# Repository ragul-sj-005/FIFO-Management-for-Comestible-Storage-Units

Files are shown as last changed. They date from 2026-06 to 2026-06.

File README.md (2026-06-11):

# FIFO Management for Comestible Storage Units

## Design and Implementation of a Smart Interface for Automating FIFO Stock Control in Comestible Storage Units

---

## Overview

This project is a Raspberry Pi based smart inventory management system designed for commercial kitchens, hotels, restaurants, canteens, and food storage facilities. The system automates the **First-In First-Out (FIFO)** inventory principle by tracking food items through QR codes, monitoring expiry times, and providing visual and audible alerts.

The system uses:

* Raspberry Pi 5
* HDMI Main Display
* 3.5-inch SPI Secondary Display
* USB Camera
* Thermal QR Printer
* Rotary Encoders
* Inductive Proximity Sensor
* Buzzer
* LED Indicators

The objective is to minimize food wastage, improve stock traceability, and simplify inventory management operations.

---

## Features

### FIFO Inventory Management

* Automatic FIFO tracking.
* Every food item receives a unique QR code.
* Oldest stock can be identified and removed first.

### QR Code Based Tracking

* Generates unique QR IDs.
* Prints QR labels using thermal printer.
* QR scanning updates inventory automatically.

### Expiry Monitoring

* Tracks shelf life of each food item.
* Detects expired inventory automatically.
* Generates alarm notifications.

### Dual Display Architecture

#### HDMI Display (Main Interface)

* Live inventory table
* Camera feed
* Item status monitoring
* Printer status
* Sensor status
* Alarm status

#### 3.5" SPI Display (Secondary Interface)

* Encoder-based setup screen
* Weight adjustment interface
* Camera preview
* Status notifications

### Weight Management

* Rotary encoder based weight selection
* Weight update after scanning QR codes
* Real-time synchronization between displays

### Alarm Management

* Buzzer alerts for expired items
* Temporary silence feature
* Automatic re-alert if expired item remains
* Permanent alarm cancellation when expired item is removed

### Shared State Synchronization

* Thread-safe state management
* Atomic JSON communication
* Inter-process communication between displays

---

# System Architecture

```
                      ┌────────────────────┐
                      │     USB Camera     │
                      └─────────┬──────────┘
                                │
                                ▼
                     ┌─────────────────────┐
                     │   HDMI Display App  │
                     │   hdmi_display.py   │
                     └─────────┬───────────┘
                               │
          ┌────────────────────┼────────────────────┐
          │                    │                    │
          ▼                    ▼                    ▼

   QR Printer         Shared State          Proximity Sensor
                         JSON File

          ▲                    ▲
          │                    │
          │                    │
          ▼                    ▼

                  Small Display App
                   small_display.py

          ▲                    ▲
          │                    │
          ▼                    ▼

      Encoder 1            Encoder 2
      (Weight)             (Item Select)
```

---

# Project Structure

```
FIFO-System/
│
├── hdmi_display.py
├── small_display.py
├── shared_state.py
│
├── README.md
│
└── assets/
    ├── images/
    └── diagrams/
```

---

# Core Modules

## 1. shared_state.py

Acts as the central communication layer between both display applications.

### Responsibilities

* Stores inventory database
* Maintains display states
* Tracks encoder values
* Handles buzzer status
* Manages QR counters
* Synchronizes data across processes

### IPC Files

```
/tmp/fifo_state.json
```

Stores system state.

```
/dev/shm/fifo_frame.npy
```

Stores live camera frames in RAM.

---

## 2. hdmi_display.py

Main application running on the HDMI display.

### Functions

* Inventory dashboard
* QR code scanning
* Camera processing
* Expiry monitoring
* Thermal printer control
* Proximity sensor handling
* Buzzer control

### Display Information

* Inventory table
* QR IDs
* Item names
* Weight
* Shelf life
* Time remaining
* Expiry status

---

## 3. small_display.py

Secondary display application.

### Functions

* Encoder interface
* Weight adjustment
* Item selection
* Camera preview
* Status messages

### Supported Modes

| Mode | Function |
| --- | --- |
| startup | System startup |
| idle | Waiting state |
| setup | Add item |
| update | Update weight |
| camera | Live camera |
| printing | QR printing |
| fresh_scan | Fresh item removed |
| expired_scan | Expired item discarded |
| timeout | Expiry alert |

---

# Hardware Components

| Component | Purpose |
| --- | --- |
| Raspberry Pi 5 | Main Controller |
| HDMI Display | Main Dashboard |
| 3.5" SPI TFT Display | Secondary Interface |
| USB Camera | QR Scanning |
| Thermal Printer | QR Label Printing |
| Rotary Encoder 1 | Weight Selection |
| Rotary Encoder 2 | Item Selection |
| Inductive Sensor | Item Detection |
| Buzzer | Expiry Alert |
| LED | Sensor Status |

---

# GPIO Configuration

## HDMI Controller

| Device | GPIO |
| --- | --- |
| Sensor | GPIO 16 |
| Buzzer | GPIO 12 |
| LED | GPIO 13 |

## Small Display

### Encoder 1

| Signal | GPIO |
| --- | --- |
| CLK | GPIO 19 |
| DT | GPIO 20 |
| SW | GPIO 5  |

### Encoder 2

| Signal | GPIO |
| --- | --- |
| CLK | GPIO 21 |
| DT | GPIO 26 |
| SW | GPIO 6  |

---

# Inventory Workflow

## Adding a New Item

1. Press SPACE.
2. System enters setup mode.
3. Encoder 2 selects food item.
4. Encoder 1 selects weight.
5. Press SPACE again.
6. QR label is printed.
7. Item is stored in inventory database.

---

## Updating an Existing Item

1. Place item near scanner.
2. QR code is detected.
3. System enters update mode.
4. Encoder 1 adjusts weight.
5. Press Encoder 1 switch.
6. Database updates weight.

---

## Expiry Detection

1. Expiry thread continuously checks inventory.
2. Expired items are flagged.
3. Buzzer activates.
4. Alert displayed on screens.
5. Scanning expired item removes it from database.

---

# Software Requirements

## Operating System

* Raspberry Pi OS Bookworm

## Python Version

```
Python 3.11+
```

## Required Libraries

```bash
pip install numpy
pip install pillow
pip install opencv-python
pip install pyzbar
pip install python-escpos
pip install rpi-lgpio
```

---

# Installation

Clone repository:

```bash
git clone https://github.com/yourusername/FIFO-Comestible-Storage.git

cd FIFO-Comestible-Storage
```

Install dependencies:

```bash
pip install -r requirements.txt
```

Run HDMI application:

```bash
python3 hdmi_display.py
```

Run Small Display:

```bash
sudo python3 small_display.py
```

---

# Communication Mechanism

The system uses a lightweight Inter-Process Communication (IPC) mechanism.

### State Communication

```
/tmp/fifo_state.json
```

Stores:

* Inventory database
* Display mode
* Encoder values
* Alarm state
* Active QR ID

### Camera Communication

```
/dev/shm/fifo_frame.npy
```

Stores live camera frames in RAM.

Benefits:

* Extremely fast
* No SD card wear
* Atomic state updates
* Reliable synchronization

---

# Safety Features

* Thread-safe shared state
* Atomic file writes
* Automatic buzzer reset
* Printer failure handling
* Camera failure recovery
* GPIO cleanup on shutdown
* QR scan cooldown protection

---

# Future Improvements

* Cloud inventory synchronization
* Mobile application integration
* RFID support
* AI-based food spoilage prediction
* Temperature and humidity monitoring
* Multi-storage unit networking
* Database backend (SQLite/PostgreSQL)
* Web dashboard

---

# Applications

* Hotels
* Restaurants
* Industrial Kitchens
* Catering Services
* Food Warehouses
* Hospitals
* Hostels
* Supermarkets

---

# Authors

Developed as part of a smart automation project for:

**FIFO Management of Comestible Storage Units**

Focused on reducing food wastage, improving traceability, and ensuring efficient stock rotation through automation.

---

# License

This project is released under the MIT License.

Feel free to use, modify, and distribute the software for educational and research purposes.

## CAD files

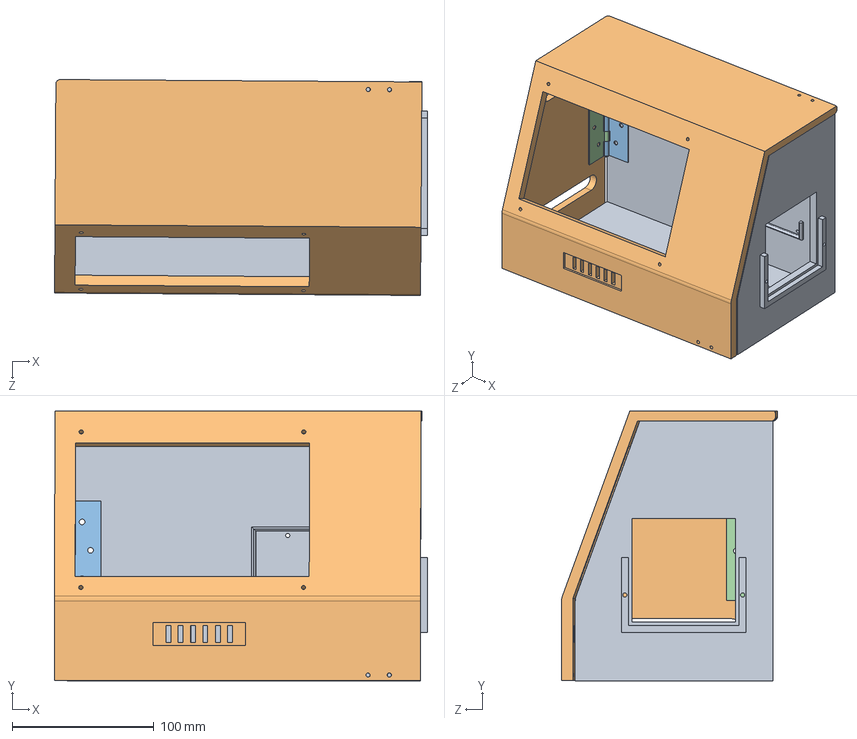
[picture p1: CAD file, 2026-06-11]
FIFO_Optimised_2.SLDASM
262.9 x 190.1 x 152.2 mm
Envelope_Opti_2_1
Envelope_Opti_2_2
Hinge_1
Hinge_2
Hinge_Centre_Rod

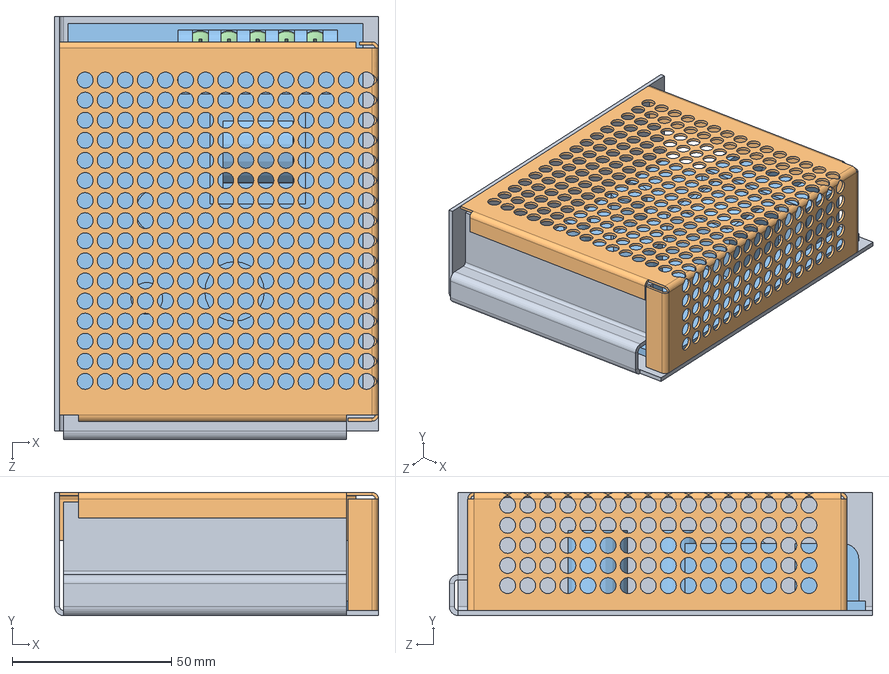
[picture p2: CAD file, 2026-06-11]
SMPS-24v.SLDASM
101.6 x 38.6 x 132.8 mm
Smps part 1-edit-00
Smps part 2-edit-00
part3-edit-00
pan cross head_am x 5

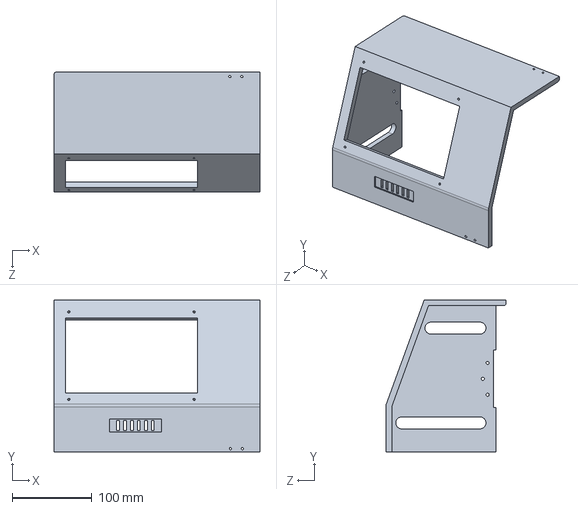
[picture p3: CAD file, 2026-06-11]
Envelope_Opti_2_2.SLDPRT
258.0 x 190.0 x 150.9 mm

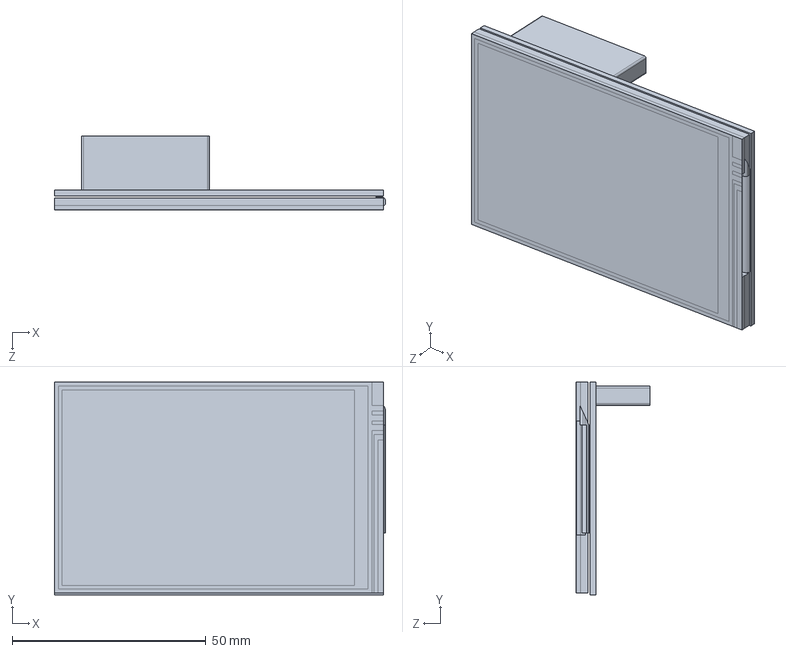
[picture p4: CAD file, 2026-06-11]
3.5' RPi TouchScreen v4.SLDPRT
85.5 x 55.0 x 19.1 mm

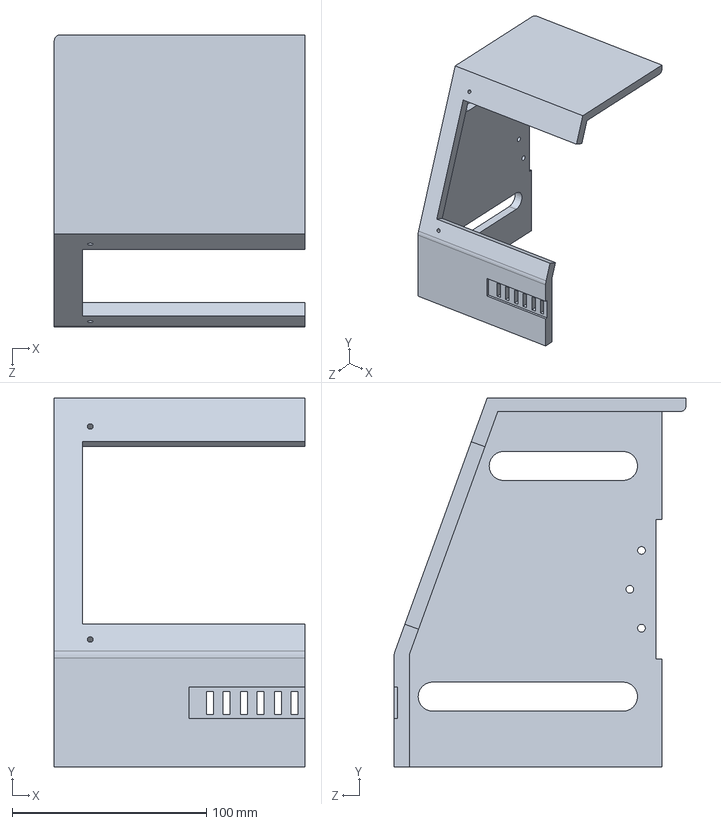
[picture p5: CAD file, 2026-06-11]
Envelope_Opti_2_2_2.SLDPRT
129.0 x 190.0 x 150.5 mm

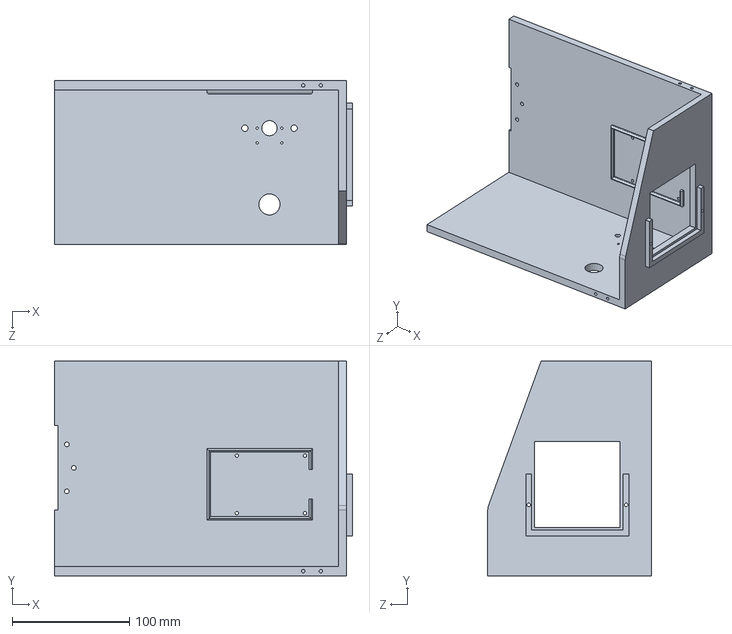
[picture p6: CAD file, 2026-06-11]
Envelope_Opti_2_1.SLDPRT
254.0 x 183.0 x 139.5 mm

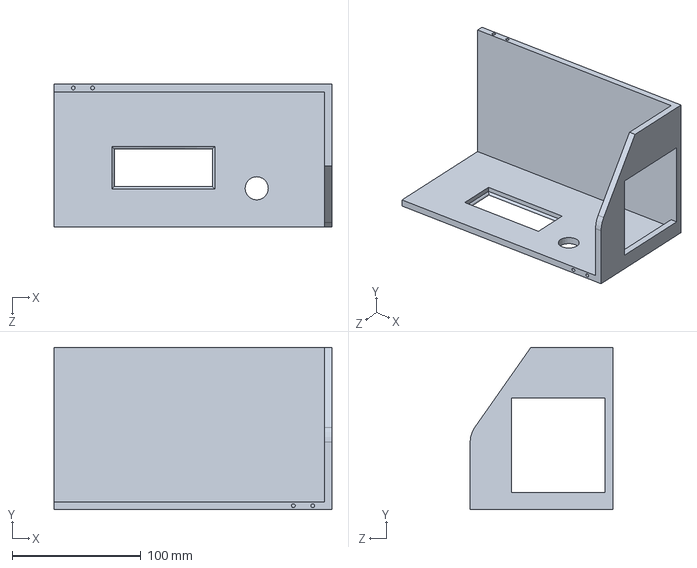
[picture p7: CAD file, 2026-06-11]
Back_Part_Mini_Review_2.SLDPRT
216.0 x 126.0 x 111.0 mm

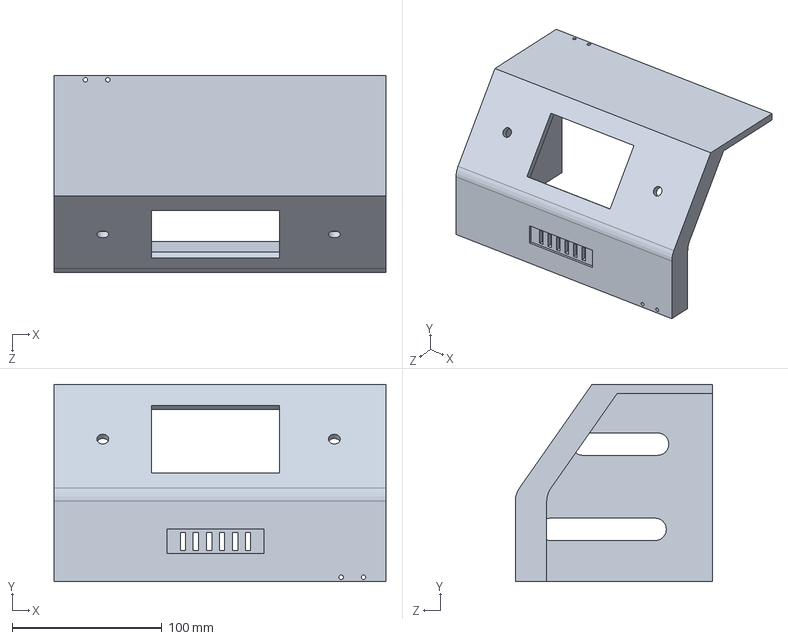
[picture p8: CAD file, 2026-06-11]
Front_Part_Mini_Review_2.SLDPRT
222.0 x 132.0 x 132.0 mm

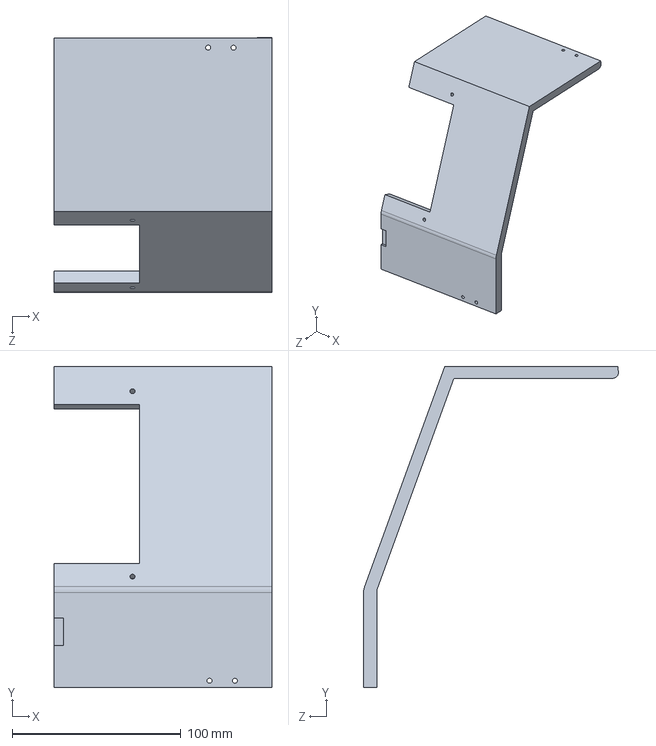
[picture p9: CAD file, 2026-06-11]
Envelope_Opti_2_2_1.SLDPRT
129.0 x 190.0 x 150.9 mm

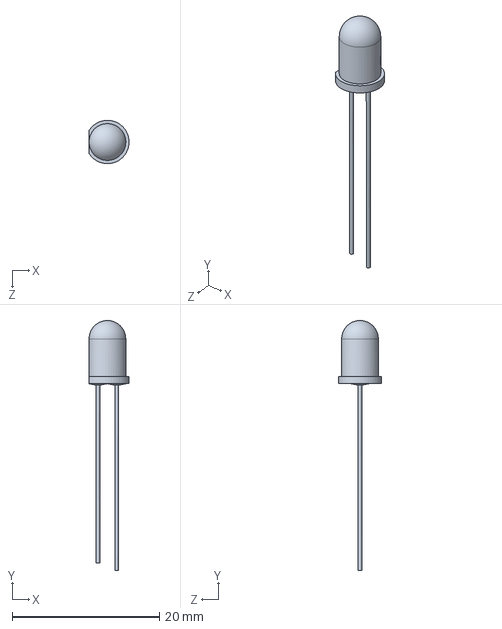
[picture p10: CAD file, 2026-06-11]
5mm_LED.SLDPRT
5.47 x 34.0 x 5.90 mm

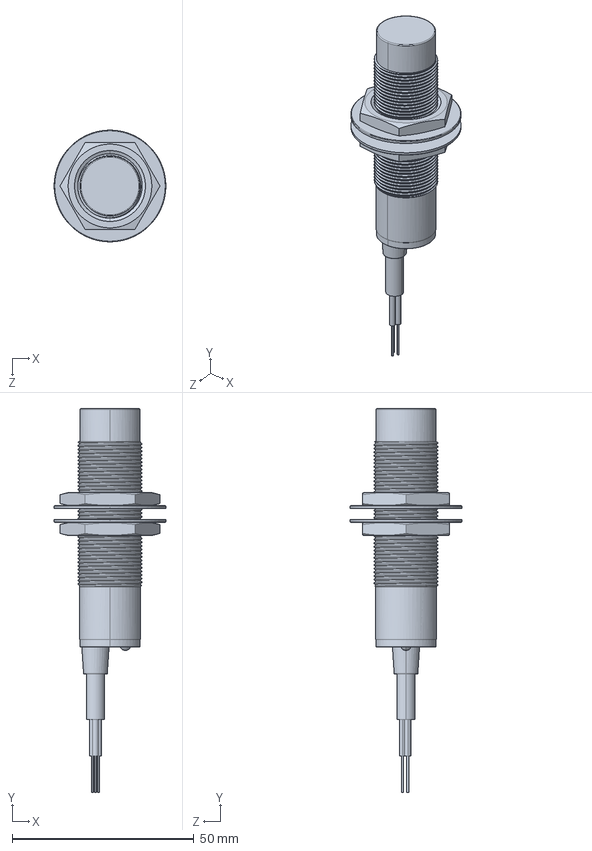
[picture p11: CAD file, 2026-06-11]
LJ18A3-8-Z.SLDPRT
30.7 x 105.5 x 30.7 mm

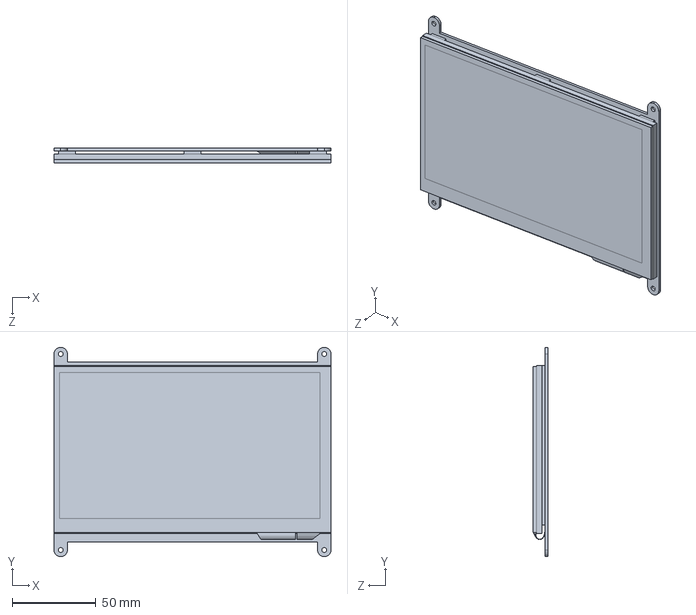
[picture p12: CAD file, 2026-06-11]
7inch Display-B 800X480px rev3.5.SLDPRT
164.9 x 124.7 x 8.75 mm

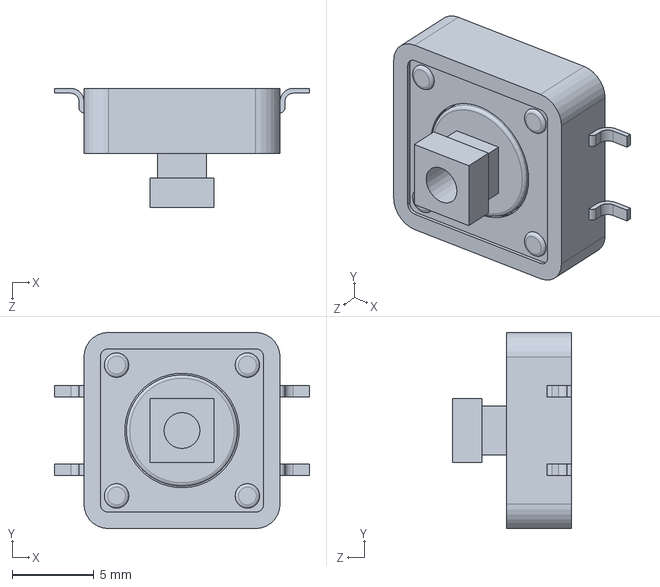
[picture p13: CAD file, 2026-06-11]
Trigger_Button.SLDPRT
15.6 x 12.0 x 7.30 mm

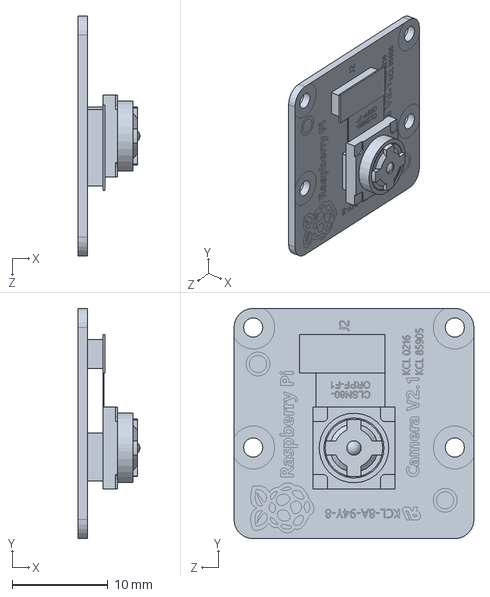
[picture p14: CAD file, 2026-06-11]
Pi_Camera.SLDPRT
6.45 x 24.0 x 25.0 mm

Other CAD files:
SMPS_Final.SLDPRT
Thermal_Printer.SLDPRT

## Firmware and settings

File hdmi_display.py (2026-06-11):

"""
hdmi_display.py  —  v4  (corrected)
═══════════════════════════════════════════════════════════════════
Main control panel — HDMI display, 800×480, fullscreen.

Hardware
─────────
  • USB Webcam       cv2.VideoCapture(0)
  • Inductive Sensor GPIO 16 BCM — active HIGH, PUD_DOWN
  • Buzzer           GPIO 12 BCM — active HIGH
  • LED              GPIO 13 BCM — active HIGH
  • Printer          /dev/ttyUSB0  9600 baud  FT232R adapter

Keyboard (temporary — replace with GPIO buttons later)
───────────────────────────────────────────────────────
  SPACE  → Button 1 — enter setup mode / confirm + print QR
  DELETE → Button 2 — remove table-selected item completely
  ESC    → Button 3 — remove active_qr_id (last scanned item) from database

Workflow
────────
  1. Startup      → GUI shown, table empty, camera blank
  2. Press SPACE  → enter setup mode (small display shows split screen)
                    Encoder 2 selects item, Encoder 1 sets weight
  3. Press SPACE  → confirm → print QR → item added to table
  4. Sensor HIGH  → camera ON, QR scanning active
  5. Scan existing QR → small display shows item+weight, Encoder 1 adjusts
                        weight, Encoder 1 SW confirms update
  6. Scan expired QR  → item removed, buzzer stops permanently for that item
  7. Press DELETE while item highlighted → remove item immediately

Table columns: QR ID | Item | Weight | Shelf Life | Time Left | Status

Buzzer
───────
  Rings once per expired item.
  Any button press silences — re-rings 60s later if item still expired.
  Scanning expired QR stops buzzer permanently for that item.

Fixes vs v3
───────────
  • GPIO.cleanup() removed from _gpio_init() — was resetting small_display's
    encoder pins at startup, causing random encoder death.
    GPIO.cleanup() is now ONLY called in the final shutdown finally block.
  • _buzzer_silenced_at defined and properly wired: silence_buzzer() records
    the timestamp so check_expiry_loop's BUZZER_RERING guard works correctly.
    Previously _buzzer_silenced_at was used but never defined → NameError crash.
  • buzzer_silenced_request flag is cleared immediately after being acted on,
    preventing it from repeatedly triggering silence_buzzer() on every poll.
"""

import logging
import os
import threading
import time
from datetime import datetime, timedelta

import cv2
import numpy as np
import tkinter as tk
from tkinter import ttk, messagebox
from PIL import Image, ImageTk

import RPi.GPIO as GPIO
from pyzbar.pyzbar import decode
from escpos.printer import Serial

import shared_state as state

# ══════════════════════════════════════════════════════════════════════════════
# LOGGING
# ══════════════════════════════════════════════════════════════════════════════
logging.basicConfig(level=logging.INFO,
                    format="%(asctime)s [%(levelname)s] %(message)s")
log = logging.getLogger("fifo.hdmi")

# ══════════════════════════════════════════════════════════════════════════════
# CONFIGURATION
# ══════════════════════════════════════════════════════════════════════════════
PIN_SENSOR      = 16
PIN_BUZZER      = 12
PIN_LED         = 13
BUZZER_DURATION = 10       # seconds buzzer rings before auto-off
BUZZER_RERING   = 60       # seconds before re-ring if item still expired

PRINTER_PORT    = "/dev/ttyUSB0"
PRINTER_BAUD    = 9600
CAMERA_INDEX    = 0
SCAN_COOLDOWN   = 2.0
MAX_ITEMS       = 20

# ══════════════════════════════════════════════════════════════════════════════
# GPIO SETUP
# ──────────────────────────────────────────────────────────────────────────────
# FIX: GPIO.cleanup() is NOT called here.
# Calling cleanup() at startup would reset the encoder pins that small_display
# already configured, causing random encoder failures and unstable pullups.
# cleanup() is only called once — in the final shutdown (see main() finally).
# ══════════════════════════════════════════════════════════════════════════════
def _gpio_init():
    GPIO.setmode(GPIO.BCM)
    GPIO.setwarnings(False)
    GPIO.setup(PIN_SENSOR, GPIO.IN,  pull_up_down=GPIO.PUD_UP)   # NC sensor — resting HIGH, LOW = triggered
    GPIO.setup(PIN_BUZZER, GPIO.OUT, initial=GPIO.LOW)
    GPIO.setup(PIN_LED,    GPIO.OUT, initial=GPIO.LOW)
    GPIO.output(PIN_BUZZER, GPIO.LOW)
    GPIO.output(PIN_LED,    GPIO.LOW)
    time.sleep(0.2)

# ══════════════════════════════════════════════════════════════════════════════
# PRINTER
# ══════════════════════════════════════════════════════════════════════════════
printer    = None
printer_ok = False

def _init_printer():
    global printer, printer_ok
    try:
        printer    = Serial(devfile=PRINTER_PORT, baudrate=PRINTER_BAUD, timeout=1)
        time.sleep(0.5)
        printer_ok = True
        log.info("Printer ready on %s", PRINTER_PORT)
    except Exception as e:
        printer_ok = False
        log.warning("Printer offline: %s", e)

# ══════════════════════════════════════════════════════════════════════════════
# BUZZER
# ──────────────────────────────────────────────────────────────────────────────
# FIX: _buzzer_silenced_at tracks when the buzzer was last silenced.
# This is used in check_expiry_loop to enforce BUZZER_RERING cooldown after
# a manual silence. Previously this variable was referenced but never defined,
# causing a NameError crash on the first expiry event.
# ══════════════════════════════════════════════════════════════════════════════
_buzzer_lock       = threading.Lock()
_buzzer_ringing    = False
_buzzer_silenced_at = [0.0]   # mutable container so inner functions can write it

def _buzzer_off_worker():
    global _buzzer_ringing
    time.sleep(BUZZER_DURATION)
    GPIO.output(PIN_BUZZER, GPIO.LOW)
    state.set_val("buzzer_active", False)
    state.write_state_file()
    with _buzzer_lock:
        _buzzer_ringing = False
    log.info("Buzzer auto-off")

def trigger_buzzer():
    global _buzzer_ringing
    with _buzzer_lock:
        if _buzzer_ringing:
            return
        _buzzer_ringing = True
    GPIO.output(PIN_BUZZER, GPIO.HIGH)
    state.set_val("buzzer_active", True)
    state.write_state_file()
    threading.Thread(target=_buzzer_off_worker, daemon=True).start()
    log.info("Buzzer triggered")

def silence_buzzer():
    """
    Silence buzzer on any button press.
    Records the silence timestamp so re-ring cooldown works correctly.
    Re-ring happens after BUZZER_RERING seconds if item is still expired.
    """
    global _buzzer_ringing
    GPIO.output(PIN_BUZZER, GPIO.LOW)
    state.set_val("buzzer_active", False)
    state.clear_all_buzzer_notified()
    state.write_state_file()
    with _buzzer_lock:
        _buzzer_ringing = False
    # FIX: record the time of silence so check_expiry_loop respects BUZZER_RERING
    _buzzer_silenced_at[0] = time.time()
    log.info("Buzzer silenced by button — will re-ring in %ds", BUZZER_RERING)

# ══════════════════════════════════════════════════════════════════════════════
# CAMERA
# ══════════════════════════════════════════════════════════════════════════════
camera = None

def _start_camera():
    global camera
    for attempt in range(5):
        # Force V4L2 backend — avoids GStreamer pipeline errors on Pi
        cam = cv2.VideoCapture(CAMERA_INDEX, cv2.CAP_V4L2)
        if cam.isOpened():
            cam.set(cv2.CAP_PROP_FRAME_WIDTH,  640)
            cam.set(cv2.CAP_PROP_FRAME_HEIGHT, 480)
            cam.set(cv2.CAP_PROP_BUFFERSIZE, 1)   # reduce buffer lag
            for _ in range(5):
                cam.read()
            camera = cam
            log.info("Camera started via V4L2 (attempt %d)", attempt + 1)
            return
        cam.release()
        time.sleep(1)
    log.warning("Camera not available — continuing without camera")

def _write_frame(frame_rgb):
    try:
        np.save(state.FRAME_FILE, frame_rgb)
    except Exception as e:
        log.warning("Frame write: %s", e)

# ══════════════════════════════════════════════════════════════════════════════
# QR DECODE — multi-strategy
# ══════════════════════════════════════════════════════════════════════════════
_last_scan = {}
_scan_lock = threading.Lock()

def _decode_qr(frame_bgr):
    gray = cv2.cvtColor(frame_bgr, cv2.COLOR_BGR2GRAY)
    blur = cv2.GaussianBlur(gray, (3, 3), 0)
    r = decode(blur)
    if r: return r
    eq = cv2.equalizeHist(blur)
    r  = decode(eq)
    if r: return r
    _, th = cv2.threshold(eq, 0, 255, cv2.THRESH_BINARY + cv2.THRESH_OTSU)
    return decode(th)

def process_frame(frame_bgr, ui_ref=None):
    db  = state.get_food_db()
    now = time.time()
    for qr in _decode_qr(frame_bgr):
        qr_id = qr.data.decode("utf-8").strip()
        x, y, w, h = qr.rect
        cv2.rectangle(frame_bgr, (x, y), (x + w, y + h), (0, 255, 0), 3)
        cv2.putText(frame_bgr, qr_id, (x, y - 10),
                    cv2.FONT_HERSHEY_SIMPLEX, 0.7, (0, 255, 0), 2)
        with _scan_lock:
            if now - _last_scan.get(qr_id, 0) < SCAN_COOLDOWN:
                continue
            _last_scan[qr_id] = now
        log.info("QR scanned: %s", qr_id)
        if qr_id in db:
            _handle_qr_scan(qr_id, db[qr_id], ui_ref)

def _handle_qr_scan(qr_id, item, ui_ref):
    """
    Scanned existing QR:
      - If expired → remove item, stop buzzer permanently
      - If fresh   → enter update mode so user can adjust weight
    """
    if item["expired"]:
        # Expired scan → remove immediately, stop buzzer for this item
        remove_item(qr_id, ui_ref=ui_ref)
        state.clear_buzzer_notified(qr_id)
        GPIO.output(PIN_BUZZER, GPIO.LOW)
        state.set_val("buzzer_active", False)
        state.write_state_file()
    else:
        # Fresh scan → enter update mode so user can adjust weight
        state.set_val("weight_grams",  item.get("weight_grams", 500))
        state.set_val("encoder_mode",  "update")
        state.set_val("active_qr_id",  qr_id)
        state.set_val("display_mode",  "update")
        state.write_state_file()
        if ui_ref:
            ui_ref.set_status(f"Updating {qr_id} — adjust weight then press ENC1", "#d29922")

# ══════════════════════════════════════════════════════════════════════════════
# ENCODER STATE SYNC
# ══════════════════════════════════════════════════════════════════════════════
def _sync_encoder_state_from_json():
    """
    Pull weight_grams and selected_item from the JSON state file into
    hdmi_display's in-process _state.

    small_display patches these keys directly into the JSON using
    _patch_state_file().  hdmi_display's in-process _state is never touched by
    those patches, so state.get("weight_grams") and state.get("selected_item")
    would otherwise always return stale startup defaults — breaking the HDMI
    UI labels AND print_qr().

    MUST be called immediately before any write_state_file() call that fires
    while encoder_mode is "setup" or "update".  Without syncing first,
    write_state_file() serialises the stale in-process values back to JSON,
    overwriting small_display's most recent encoder patch (the "bulldozer"
    race that made item changes appear to be ignored).
    """
    try:
        _raw = state.read_state_file()
        _w = _raw.get("weight_grams")
        _i = _raw.get("selected_item")
        if _w is not None:
            state.set_val("weight_grams",  _w)
        if _i is not None:
            state.set_val("selected_item", _i)
    except Exception as _e:
        log.warning("_sync_encoder_state_from_json: %s", _e)


# ══════════════════════════════════════════════════════════════════════════════
# CORE LOGIC
# ══════════════════════════════════════════════════════════════════════════════
def print_qr(ui_ref=None):
    global printer_ok
    db = state.get_food_db()
    if len(db) >= MAX_ITEMS:
        messagebox.showwarning("Full", f"Maximum {MAX_ITEMS} items reached.")
        return

    item_name  = state.get("selected_item")
    weight     = state.get("weight_grams")
    shelf_life = state.ITEMS.get(item_name, 60)
    qr_id      = state.next_qr_id(item_name)
    now        = datetime.now()
    expiry_dt  = now + timedelta(seconds=shelf_life)

    db[qr_id] = {
        "id":           qr_id,
        "item":         item_name,
        "weight_grams": weight,
        "shelf_life":   shelf_life,
        "created":      now,
        "expiry":       expiry_dt,
        "expired":      False,
    }
    state.update_food_db(db)

    # Exit setup mode
    state.set_val("encoder_mode", None)
    state.set_val("display_mode", "printing")
    state.write_state_file()

    if ui_ref:
        ui_ref.set_status(f"Printing {qr_id}...", "#d29922")

    if not printer_ok:
        _init_printer()

    if printer_ok:
        try:
            printer.set(align="center")
            printer.qr(qr_id, native=True, size=8)
            printer.text(
                f"\nITEM  : {item_name}\n"
                f"WEIGHT: {weight}g\n"
                f"SHELF : {shelf_life}s\n"
                f"ID    : {qr_id}\n"
                f"TIME  : {now.strftime('%H:%M:%S')}\n"
            )
            printer.ln(4)
            printer.cut()
            printer.device.flush()
            log.info("Printed: %s", qr_id)
            if ui_ref:
                ui_ref.set_status(f"Printed {qr_id} ✓", "#22c55e")
        except Exception as e:
            printer_ok = False
            log.error("Print error: %s", e)
            if ui_ref:
                ui_ref.set_status(f"Printer error: {e}", "#ef4444")
    else:
        if ui_ref:
            ui_ref.set_status("QR saved — printer offline", "#f59e0b")

    threading.Timer(2.0, lambda: (
        state.set_val("display_mode", "idle"),
        state.write_state_file()
    )).start()


def remove_item(qr_id: str, ui_ref=None):
    db = state.get_food_db()
    if qr_id not in db:
        return
    was_expired = db[qr_id]["expired"]
    del db[qr_id]
    state.clear_buzzer_notified(qr_id)
    state.update_food_db(db)
    mode   = "expired_scan" if was_expired else "fresh_scan"
    colour = "#ef4444" if was_expired else "#22c55e"
    label  = "EXPIRED removed" if was_expired else f"{qr_id} removed ✓"
    state.set_val("display_mode", mode)
    state.set_val("encoder_mode", None)
    state.set_val("active_qr_id", None)
    state.write_state_file()
    if ui_ref:
        ui_ref.set_status(label, colour)
    log.info("Removed %s", qr_id)
    threading.Timer(2.0, lambda: (
        state.set_val("display_mode", "idle"),
        state.write_state_file()
    )).start()

# ══════════════════════════════════════════════════════════════════════════════
# BACKGROUND THREADS
# ══════════════════════════════════════════════════════════════════════════════
def check_expiry_loop():
    """
    Runs every second. Marks items expired and triggers the buzzer.

    Re-ring logic:
      - never_buzzed  → ring immediately
      - rering_ok     → ring again only if BOTH:
          (a) BUZZER_RERING seconds have passed since last ring, AND
          (b) BUZZER_RERING seconds have passed since the buzzer was
              manually silenced (so pressing silence gives a full 60s
              of quiet, not just until the next 60s ring window)
    """
    last_buzz_time = {}    # qr_id → time of last buzz (for re-ring)
    while True:
        try:
            now    = datetime.now()
            db     = state.get_food_db()
            changed  = False
            to_buzz  = []
            now_ts   = time.time()

            for qr_id, item in db.items():
                # Parse expiry safely — may be datetime or ISO string after restart
                _exp = (item["expiry"] if isinstance(item["expiry"], datetime)
                        else datetime.fromisoformat(str(item["expiry"])))
                if not item["expired"] and now >= _exp:
                    item["expired"] = True
                    changed = True

                if item["expired"]:
                    last_t       = last_buzz_time.get(qr_id, 0)
                    silenced     = _buzzer_silenced_at[0]
                    never_buzzed = (last_t == 0)
                    # Both the last ring AND the last silence must be old enough
                    rering_ok    = (
                        (now_ts - last_t   >= BUZZER_RERING) and
                        (now_ts - silenced >= BUZZER_RERING)
                    )
                    if never_buzzed or rering_ok:
                        to_buzz.append(qr_id)

            if changed:
                state.update_food_db(db)
                if state.get("display_mode") == "idle":
                    state.set_val("display_mode", "timeout")
                state.write_state_file()
                threading.Timer(5.0, lambda: (
                    state.set_val("display_mode", "idle")
                    if state.get("display_mode") == "timeout" else None,
                    state.write_state_file()
                )).start()

            for qr_id in to_buzz:
                state.mark_buzzer_notified(qr_id)
                last_buzz_time[qr_id] = time.time()
                trigger_buzzer()

        except Exception as e:
            log.error("expiry_loop: %s", e)
        time.sleep(1)


def proximity_loop(ui_ref=None):
    prev = None
    while True:
        try:
            s1 = GPIO.input(PIN_SENSOR) == GPIO.LOW
            time.sleep(0.02)
            s2 = GPIO.input(PIN_SENSOR) == GPIO.LOW
            detected = s1 and s2

            if detected != prev:
                prev = detected
                state.set_val("proximity_detected", detected)
                GPIO.output(PIN_LED, GPIO.HIGH if detected else GPIO.LOW)

                if detected:
                    state.set_val("display_mode", "camera")
                    if ui_ref:
                        ui_ref.root.after(0, lambda: ui_ref.set_status(
                            "Object detected — scanning...", "#00d4aa"))
                else:
                    if state.get("display_mode") == "camera":
                        state.set_val("display_mode", "idle")
                    if ui_ref:
                        ui_ref.root.after(0, lambda: ui_ref.set_status(
                            "Ready", "#9ca3af"))

                state.write_state_file()
        except Exception as e:
            log.error("proximity_loop: %s", e)
        time.sleep(0.05)
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

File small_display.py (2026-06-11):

"""
small_display.py  —  v3
────────────────────────────────────────
Secondary display — writes directly to /dev/fb1 (3.5" SPI screen, 480×320).

Launch:
    sudo python3 small_display.py

Display modes
─────────────
  startup      → SYSTEM READY
  idle         → SCAN TO REMOVE  + active/expired counts
  setup        → SPLIT SCREEN: top=item name, bottom=weight  (encoder input)
  update       → SPLIT SCREEN: top=item name, bottom=weight  (weight edit)
  camera       → live feed from FRAME_FILE
  printing     → ITEM ADDED
  fresh_scan   → FRESH REMOVED
  expired_scan → EXPIRED DISCARD
  timeout      → TIMEOUT CHECK ITEM

Encoder GPIO (BCM)
───────────────────
  ENC1_CLK = 17   ENC1_DT = 4    ENC1_SW = 5    ← Weight
  ENC2_CLK = 23   ENC2_DT = 24   ENC2_SW = 6    ← Item

External buttons (keyboard keys for now)
──────────────────────────────────────────
  SPACE  → confirm + print QR   (Button 1)
  DELETE → remove scanned item  (Button 2)

Buzzer behaviour
─────────────────
  Rings when item expires (once per item).
  Any button press silences it — but it re-rings after 60s if item still expired.
  Scanning the expired item's QR stops it permanently for that item.
"""

import os
import sys
import time
import threading
import logging
from datetime import datetime

import numpy as np
from PIL import Image, ImageDraw, ImageFont
import RPi.GPIO as GPIO

import shared_state as state

logging.basicConfig(
    filename="/tmp/fifo_errors.log",
    level=logging.WARNING,
    format="%(asctime)s [%(levelname)s] %(message)s",
)
log = logging.getLogger("fifo.small")

# ══════════════════════════════════════════════════════════════════════════════
# DISPLAY CONFIG
# ══════════════════════════════════════════════════════════════════════════════
FB_DEV    = "/dev/fb1"
FB_WIDTH  = 480
FB_HEIGHT = 320
POLL_MS   = 200
CAM_MS    = 50

C_BG     = ( 10,  14,  20)
C_PANEL  = ( 22,  27,  34)
C_WHITE  = (230, 237, 243)
C_GREEN  = ( 63, 185,  80)
C_RED    = (248,  81,  73)
C_ORANGE = (210, 153,  34)
C_ACCENT = (  0, 212, 170)
C_AMBER  = (234, 179,   8)
C_SUB    = (100, 116, 139)
C_BLACK  = (  0,   0,   0)

STATE_MAP = {
    "startup":      (["SYSTEM",  "READY"],        C_ACCENT),
    "idle":         (["SCAN TO", "REMOVE"],        C_WHITE),
    "setup":        (["SELECT",  "ITEM+WT"],       C_AMBER),
    "update":       (["ADJUST",  "WEIGHT"],        C_ACCENT),
    "printing":     (["ITEM",    "ADDED"],         C_GREEN),
    "fresh_scan":   (["FRESH",   "REMOVED"],       C_GREEN),
    "expired_scan": (["EXPIRED", "DISCARD"],       C_RED),
    "timeout":      (["TIMEOUT", "CHECK ITEM"],    C_ORANGE),
}

# ══════════════════════════════════════════════════════════════════════════════
# GPIO — ENCODERS
# Polled in main loop — same approach as the working sample code.
# Local variables _local_item_idx and _local_weight are the single source of
# truth for encoder values inside small_display. They are written to shared
# state only on confirmation (ENC1_SW press or SPACE from hdmi_display).
# This prevents hdmi_display's periodic state writes from overwriting changes.
# ══════════════════════════════════════════════════════════════════════════════
ENC1_CLK = 19
ENC1_DT  = 20
ENC1_SW  = 5

ENC2_CLK = 21
ENC2_DT  = 26
ENC2_SW  = 6

# Local encoder state — owned by small_display only
_local_item_idx = 0
_local_weight   = 500
_enc1_last_clk  = 1
_enc2_last_clk  = 1
_enc1_sw_last   = 1
_enc2_sw_last   = 1

def _setup_gpio():
    GPIO.setwarnings(False)
    try:
        GPIO.cleanup()
    except Exception:
        pass
    GPIO.setmode(GPIO.BCM)
    GPIO.setwarnings(False)
    for pin in [ENC1_CLK, ENC1_DT, ENC1_SW, ENC2_CLK, ENC2_DT, ENC2_SW]:
        GPIO.setup(pin, GPIO.IN, pull_up_down=GPIO.PUD_UP)

def _poll_encoders():
    """
    Poll both encoders and push buttons.
    Called every 5ms from main loop — same as the working sample code.
    Updates local variables directly; writes to shared state only on SW press.
    Returns True if any value changed (triggers redraw).
    """
    global _local_item_idx, _local_weight
    global _enc1_last_clk, _enc2_last_clk
    global _enc1_sw_last,  _enc2_sw_last
    changed = False
    enc_mode = state.get("encoder_mode")

    # ── Encoder 1 — Weight ────────────────────────────────────────────────────
    clk1 = GPIO.input(ENC1_CLK)
    if clk1 != _enc1_last_clk:
        dt1 = GPIO.input(ENC1_DT)
        if enc_mode in ("setup", "update"):
            if dt1 != clk1:
                _local_weight = min(_local_weight + 100, 5000)
            else:
                _local_weight = max(_local_weight - 100, 100)
            # Write to shared state immediately so hdmi_display sees it
            state.set_val("weight_grams", _local_weight)
            state.write_state_file()
            changed = True
    _enc1_last_clk = clk1

    # ── Encoder 2 — Item ──────────────────────────────────────────────────────
    clk2 = GPIO.input(ENC2_CLK)
    if clk2 != _enc2_last_clk:
        dt2 = GPIO.input(ENC2_DT)
        if enc_mode == "setup":
            if dt2 != clk2:
                _local_item_idx = (_local_item_idx + 1) % len(state.ITEM_NAMES)
            else:
                _local_item_idx = (_local_item_idx - 1) % len(state.ITEM_NAMES)
            state.set_val("selected_item", state.ITEM_NAMES[_local_item_idx])
            state.write_state_file()
            changed = True
    _enc2_last_clk = clk2

    # ── Encoder 1 SW — confirm weight update / silence buzzer ─────────────────
    sw1 = GPIO.input(ENC1_SW)
    if sw1 == 0 and _enc1_sw_last == 1:   # falling edge = button pressed
        if enc_mode == "update":
            _confirm_weight_update()
        _silence_buzzer_temp()
        changed = True
    _enc1_sw_last = sw1

    # ── Encoder 2 SW — silence buzzer ─────────────────────────────────────────
    sw2 = GPIO.input(ENC2_SW)
    if sw2 == 0 and _enc2_sw_last == 1:
        _silence_buzzer_temp()
    _enc2_sw_last = sw2

    return changed

def _sync_local_from_state():
    """
    Sync local encoder vars from shared state when entering setup/update mode.
    Ensures local vars start from the current shared state values.
    """
    global _local_item_idx, _local_weight
    item = state.get("selected_item")
    if item in state.ITEM_NAMES:
        _local_item_idx = state.ITEM_NAMES.index(item)
    _local_weight = state.get("weight_grams") or 500

# ══════════════════════════════════════════════════════════════════════════════
# BUZZER SILENCE
# ══════════════════════════════════════════════════════════════════════════════
_buzzer_silence_timer = None
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

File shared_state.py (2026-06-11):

"""
shared_state.py  —  v4  (final, ready-to-use)
══════════════════════════════════════════════════════════════════════════════
Single source of truth shared between hdmi_display.py and small_display.py.
Both programs import this module.  hdmi_display.py uses it in-process;
small_display.py reads the JSON file hdmi_display writes to disk.

IPC paths
──────────
  STATE_FILE  /tmp/fifo_state.json       — JSON, written atomically
  FRAME_FILE  /dev/shm/fifo_frame.npy   — camera frame stored in RAM
                                           (zero SD card wear, ~0.1 ms writes)

State keys
──────────
  food_db                  dict  qr_id → item dict
  display_mode             str   startup | idle | setup | update | camera |
                                 printing | fresh_scan | expired_scan | timeout
  proximity_detected       bool
  buzzer_active            bool
  qr_counter               int   auto-increment for QR IDs
  selected_item            str   current encoder-2 selection
  weight_grams             int   current encoder-1 selection
  encoder_mode             str   "setup" | "update" | None
  active_qr_id             str   qr_id being updated in update mode
  buzzer_notified          set   qr_ids that have already triggered the buzzer
  buzzer_silenced_request  bool  flag set by small_display, polled by hdmi_display

Pi 5 note
──────────
  RPi.GPIO does not fully support Pi 5.
  Install the drop-in shim:  pip install rpi-lgpio
  No code changes needed — it replaces RPi.GPIO transparently.
"""

import copy
import json
import logging
import os
import threading
from datetime import datetime

logging.basicConfig(
    filename="/tmp/fifo_errors.log",
    level=logging.WARNING,
    format="%(asctime)s [%(levelname)s] %(message)s",
)
log = logging.getLogger("fifo")

# ── IPC paths ──────────────────────────────────────────────────────────────────
STATE_FILE = "/tmp/fifo_state.json"
FRAME_FILE = "/dev/shm/fifo_frame.npy"   # RAM-backed — zero SD card wear

# ── Item catalogue  {name: shelf_life_seconds} ────────────────────────────────
ITEMS = {
    "CHICKEN":  60,
    "RICE":     60,
    "MUTTON":   60,
    "FISH":     60,
    "MUSHROOM": 60,
    "PANEER":   60,
}
ITEM_NAMES = list(ITEMS.keys())   # ordered list for encoder cycling

# ── Weight config ──────────────────────────────────────────────────────────────
WEIGHT_MIN  = 100
WEIGHT_MAX  = 5000
WEIGHT_STEP = 100

# ── Internal lock ──────────────────────────────────────────────────────────────
_lock = threading.Lock()

# ── Master in-process state ────────────────────────────────────────────────────
_state = {
    "food_db":                 {},
    "display_mode":            "startup",
    "proximity_detected":      False,
    "buzzer_active":           False,
    "qr_counter":              1,
    "selected_item":           ITEM_NAMES[0],
    "weight_grams":            500,
    "encoder_mode":            None,
    "active_qr_id":            None,
    "buzzer_notified":         set(),
    "buzzer_silenced_request": False,
    "_last_written":           None,
}


# ══════════════════════════════════════════════════════════════════════════════
# THREAD-SAFE ACCESSORS
# ══════════════════════════════════════════════════════════════════════════════

def get(key):
    with _lock:
        return _state.get(key)

def set_val(key, value):
    with _lock:
        _state[key] = value

def get_food_db():
    with _lock:
        return copy.deepcopy(_state["food_db"])

def update_food_db(db):
    with _lock:
        _state["food_db"] = copy.deepcopy(db)

def next_qr_id(item_name):
    with _lock:
        idx = _state["qr_counter"]
        _state["qr_counter"] += 1
        return f"{item_name}_{idx}"

def alarm_active():
    with _lock:
        return any(item["expired"] for item in _state["food_db"].values())


# ── Buzzer notification helpers ───────────────────────────────────────────────

def mark_buzzer_notified(qr_id: str):
    with _lock:
        _state["buzzer_notified"].add(qr_id)

def is_buzzer_notified(qr_id: str) -> bool:
    with _lock:
        return qr_id in _state["buzzer_notified"]

def clear_buzzer_notified(qr_id: str):
    with _lock:
        _state["buzzer_notified"].discard(qr_id)

def clear_all_buzzer_notified():
    """Called when user silences buzzer — allows re-ring after BUZZER_RERING s."""
    with _lock:
        _state["buzzer_notified"].clear()


# ── Encoder helpers ───────────────────────────────────────────────────────────

def next_item():
    """Encoder 2 clockwise — advance item selection."""
    with _lock:
        idx = ITEM_NAMES.index(_state["selected_item"])
        _state["selected_item"] = ITEM_NAMES[(idx + 1) % len(ITEM_NAMES)]

def prev_item():
    """Encoder 2 counter-clockwise — go back in item list."""
    with _lock:
        idx = ITEM_NAMES.index(_state["selected_item"])
        _state["selected_item"] = ITEM_NAMES[(idx - 1) % len(ITEM_NAMES)]

def increase_weight():
    with _lock:
        _state["weight_grams"] = min(_state["weight_grams"] + WEIGHT_STEP, WEIGHT_MAX)

def decrease_weight():
    with _lock:
        _state["weight_grams"] = max(_state["weight_grams"] - WEIGHT_STEP, WEIGHT_MIN)


# ══════════════════════════════════════════════════════════════════════════════
# IPC — JSON STATE FILE  (atomic write via tmp → replace)
# ══════════════════════════════════════════════════════════════════════════════

def _serialize_db(db):
    out = {}
    for k, v in db.items():
        out[k] = {
            "id":           v["id"],
            "item":         v["item"],
            "weight_grams": v.get("weight_grams", 0),
            "shelf_life":   v.get("shelf_life", 60),
            "created":      v["created"].isoformat() if isinstance(v["created"], datetime) else str(v["created"]),
            "expiry":       v["expiry"].isoformat()  if isinstance(v["expiry"],  datetime) else str(v["expiry"]),
            "expired":      v["expired"],
        }
    return out

def _build_payload():
    return {
        "display_mode":            _state["display_mode"],
        "proximity_detected":      _state["proximity_detected"],
        "buzzer_active":           _state["buzzer_active"],
        "food_db":                 _serialize_db(_state["food_db"]),
        "selected_item":           _state["selected_item"],
        "weight_grams":            _state["weight_grams"],
        "encoder_mode":            _state["encoder_mode"],
        "active_qr_id":            _state["active_qr_id"],
        "buzzer_silenced_request": _state["buzzer_silenced_request"],
    }
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
